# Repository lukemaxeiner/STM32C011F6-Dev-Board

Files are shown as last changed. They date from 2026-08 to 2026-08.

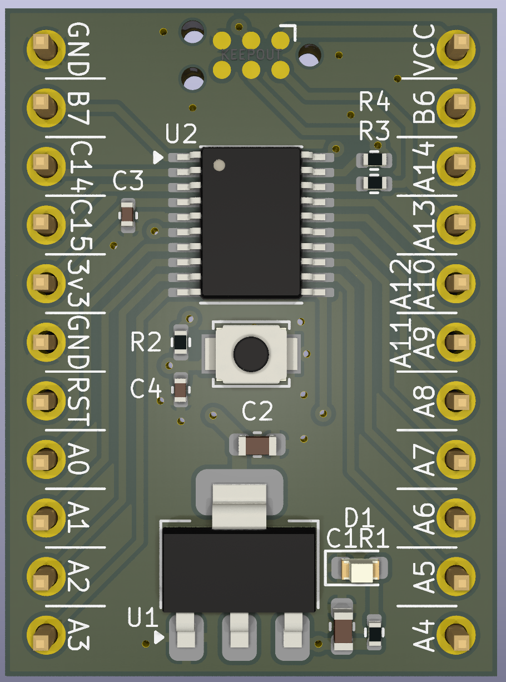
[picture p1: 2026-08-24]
STM32C011F6_PCB_Picture.png

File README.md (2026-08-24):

# STM32C011F6-Dev-Board
A development board for the STM32C011F6 for use on a breadboard. It has power regulation, SWD programming capabilities, a reset button, and power LED. All GPIO pins are put to a broken out header pin. Resistors are added on SWD pins to improve signal integrety, allowing for more versatility in its usage.

The input voltage pin accepts between 3.3 and 15V, and the microcontroller can run on an input voltage as low as 2V4. The microcontroller runs on 3V3 GPIO signals and power under optimal conditions. Across all output pins and power pins, the total power draw through the VCC pin is 3.3 Watts, and the total current draw out of any individual pin is 20mA.

This board is 0.84"x1.14", and fits on a breadboard when male pin headers are soldered onto the board. 

Below is the schematic for the dev board, created in KiCad 9.0

STM32C011F6_Schematic

Fully rendered image of the PCB design

STM32C011F6_PCB_Picture

PCB design file

PCB_Design

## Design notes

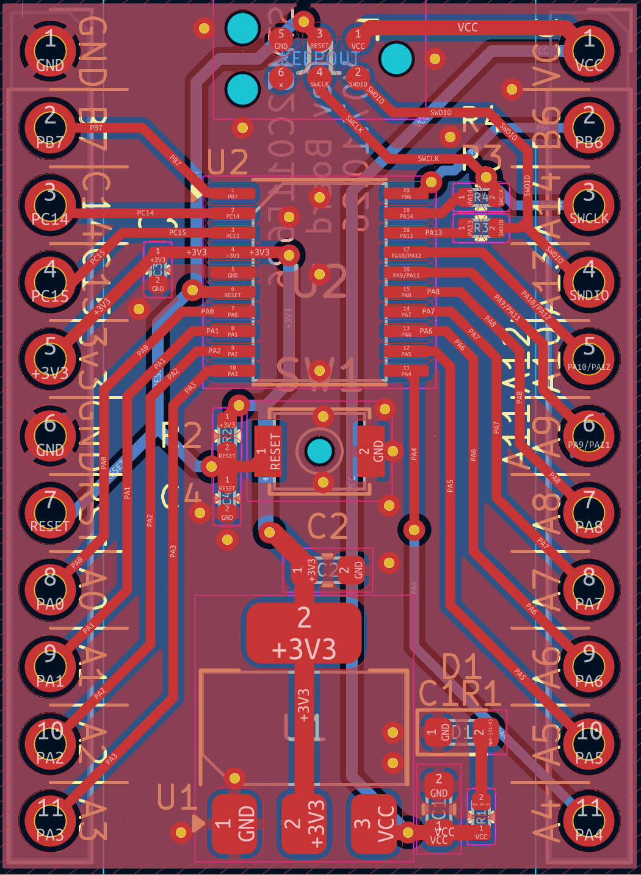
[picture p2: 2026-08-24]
PCB_Design.png

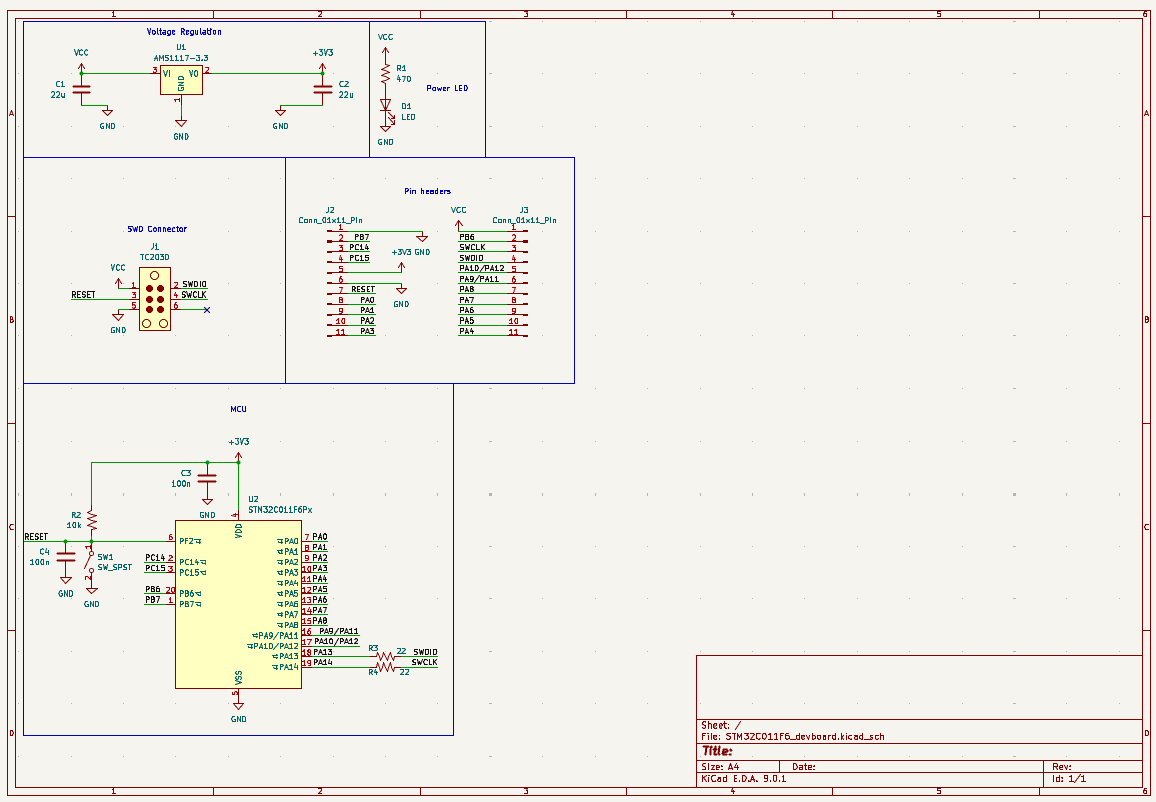
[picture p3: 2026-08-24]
STM32C011F6_Schematic.png

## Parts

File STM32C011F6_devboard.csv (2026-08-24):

Reference | Value | Footprint | Datasheet | Qty | DNP | Exclude from BOM | Exclude from Board
C1,C2 | 22u | Capacitor_SMD:C_0603_1608Metric | ~ | 2
C3,C4 | 100n | Capacitor_SMD:C_0402_1005Metric | ~ | 2
D1 | LED | LED_SMD:LED_0603_1608Metric | ~ | 1
J1 | TC2030 | Connector:Tag-Connect_TC2030-IDC-NL_2x03_P1.27mm_Vertical | https://www.tag-connect.com/wp-content/uploads/bsk-pdf-manager/2019/12/TC2030-IDC-NL-Datasheet-Rev-B.pdf | 1 |  | Excluded from BOM
J2,J3 | Conn_01x11_Pin | Connector_PinHeader_2.54mm:PinHeader_1x11_P2.54mm_Vertical | ~ | 2
R1 | 470 | Resistor_SMD:R_0402_1005Metric | ~ | 1
R2 | 10k | Resistor_SMD:R_0402_1005Metric | ~ | 1
R3,R4 | 22 | Resistor_SMD:R_0402_1005Metric | ~ | 2
SW1 | SW_SPST | Button_Switch_SMD:SW_SPST_B3U-1000P-B | ~ | 1
U1 | AMS1117-3.3 | Package_TO_SOT_SMD:SOT-223-3_TabPin2 | http://www.advanced-monolithic.com/pdf/ds1117.pdf | 1
U2 | STM32C011F6Px | Package_SO:TSSOP-20_4.4x6.5mm_P0.65mm | https://www.st.com/resource/en/datasheet/stm32c011f6.pdf | 1

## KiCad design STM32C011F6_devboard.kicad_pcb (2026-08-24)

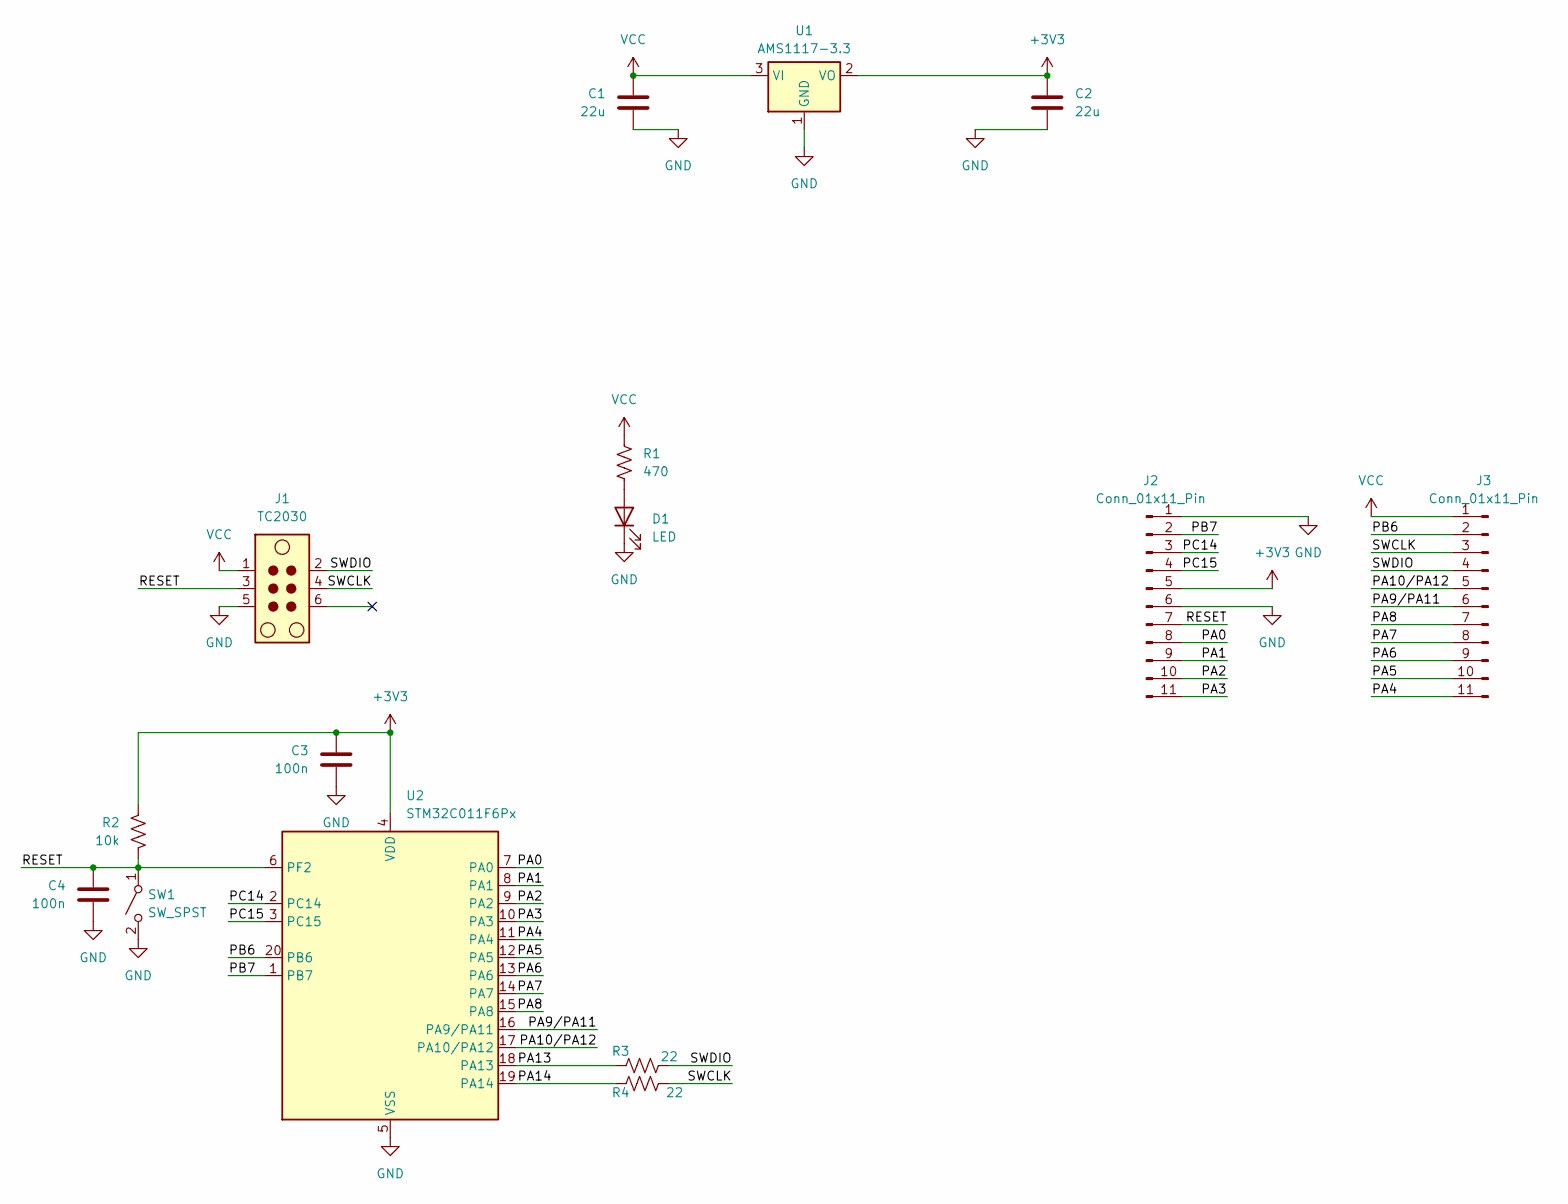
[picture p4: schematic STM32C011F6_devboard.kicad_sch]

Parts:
C1, C2: 22u; C_0603_1608Metric
C3, C4: 100n; C_0402_1005Metric
D1: LED; LED_0603_1608Metric
J1: TC2030; Tag-Connect_TC2030-IDC-NL_2x03_P1.27mm_Vertical
J2, J3: Conn_01x11_Pin; PinHeader_1x11_P2.54mm_Vertical
R1: 470; R_0402_1005Metric
R2: 10k; R_0402_1005Metric
R3, R4: 22; R_0402_1005Metric
SW1: SW_SPST; SW_SPST_B3U-1000P-B
U1: AMS1117-3.3; SOT-223-3_TabPin2
U2: STM32C011F6Px; TSSOP-20_4.4x6.5mm_P0.65mm

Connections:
+3V3: C2.1, C3.1, J2.5, R2.1, U1.2 (VO), U2.4 (VDD)
/PA0: J2.8, U2.7 (PA0)
/PA1: J2.9, U2.8 (PA1)
/PA2: J2.10, U2.9 (PA2)
/PA3: J2.11, U2.10 (PA3)
/PA4: J3.11, U2.11 (PA4)
/PA5: J3.10, U2.12 (PA5)
/PA6: J3.9, U2.13 (PA6)
/PA7: J3.8, U2.14 (PA7)
/PA8: J3.7, U2.15 (PA8)
/PA9/PA11: J3.6, U2.16 (PA9/PA11)
/PA10/PA12: J3.5, U2.17 (PA10/PA12)
/PA13: R3.1, U2.18 (PA13)
/PA14: R4.1, U2.19 (PA14)
/PB6: J3.2, U2.20 (PB6)
/PB7: J2.2, U2.1 (PB7)
/PC14: J2.3, U2.2 (PC14)
/PC15: J2.4, U2.3 (PC15)
/RESET: C4.1, J1.3, J2.7, R2.2, SW1.1 (A), U2.6 (PF2)
/SWCLK: J1.4, J3.3, R4.2
/SWDIO: J1.2, J3.4, R3.2
GND: C1.2, C2.2, C3.2, C4.2, D1.1 (K), J1.5, J2.1, J2.6, SW1.2 (B), U1.1 (GND), U2.5 (VSS)
unnamed: D1.2 (A), R1.2
VCC: C1.1, J1.1, J3.1, R1.1, U1.3 (VI)

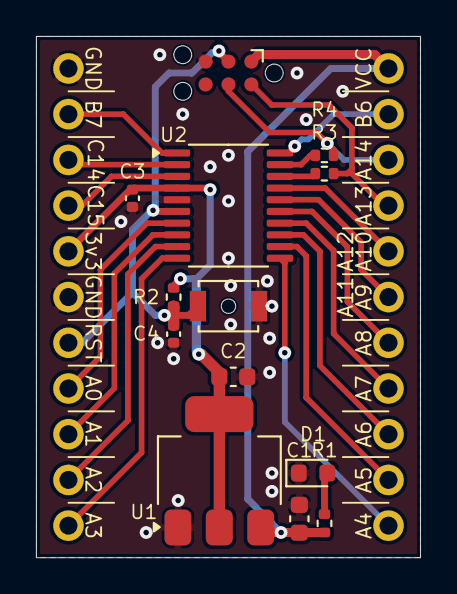
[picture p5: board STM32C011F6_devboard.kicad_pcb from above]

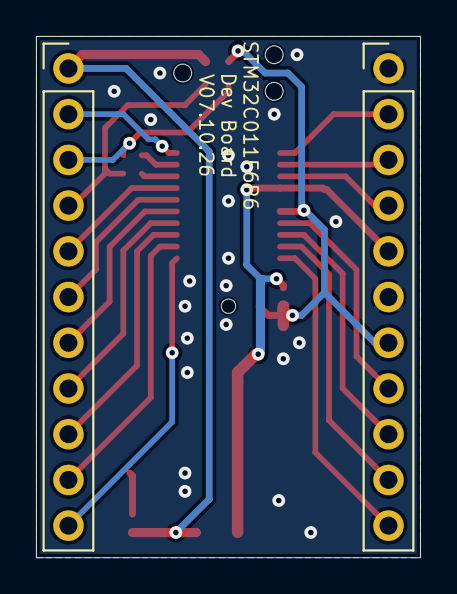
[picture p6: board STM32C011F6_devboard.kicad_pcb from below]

Board: 2 copper layers, 21.3 x 29.0 mm, 15 parts (2 on the bottom side), 24 nets.

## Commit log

2026-08-24 Completed Project Files
    [STM32C011F6_devboard-B_Cu.gbr, STM32C011F6_devboard-B_Mask.gbr, STM32C011F6_devboard-B_Paste.gbr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]
2026-08-24 Update README with schematic and PCB images
